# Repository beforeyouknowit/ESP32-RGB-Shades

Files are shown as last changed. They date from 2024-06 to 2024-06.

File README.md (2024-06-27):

# ESP32 RGB Shades
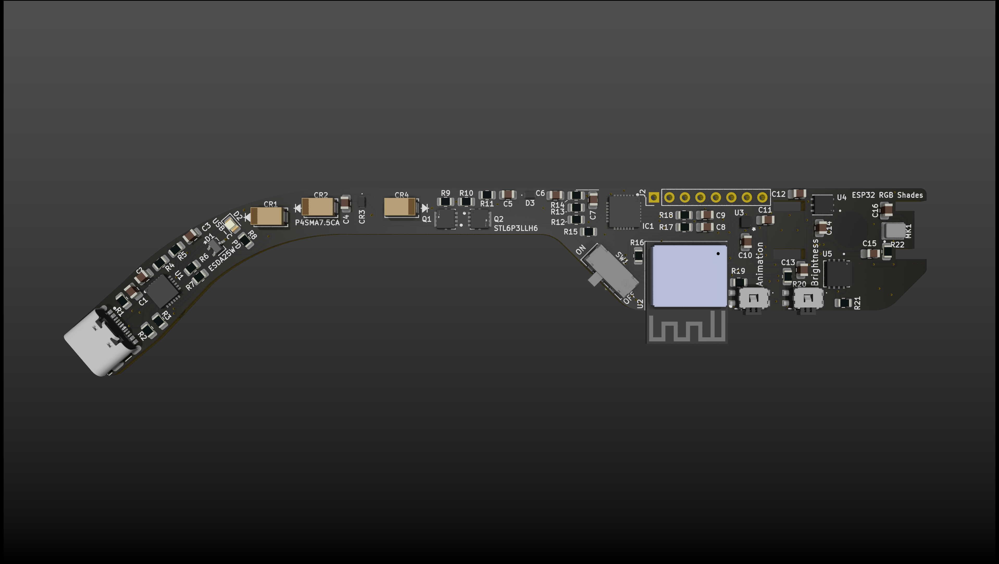
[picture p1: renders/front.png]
ESP32 RGB Shades front printed circuit board render

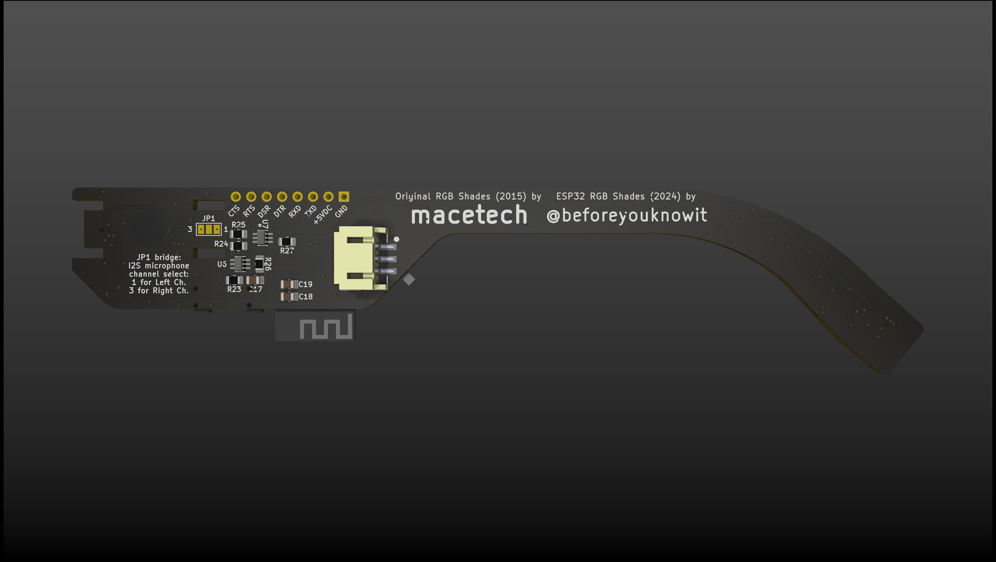
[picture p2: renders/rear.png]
ESP32 RGB Shades rear printed circuit board render


This repo currently represents an electronics update, based on the  ESP32 Pico Mini, as a redesign of [macetech/RGBShades](https://github.com/macetech/RGBShades) from 2015.

I was one of the Kickstarter backers of macetech's original campaign for "RGB Shades", described here: https://www.kickstarter.com/projects/macetech/rgb-led-shades

Redesigned in KiCad 8.x, based on original Eagle files from Macetech's website.

## Features
New electronics include:
- USB-C PD via STUSB4500 IC, which negotiates with USB-C PD supplies (e.g. modern power bank batteries and wall adapters) for 20V output, up to 5A, or 100W.
- TDK ICS-43434 microphone, with I2S digital output, for onboard audio analysis and beat detection.
- Jumper for selecting microphone digital output as left (default) or right channel audio over I2S.
- 5V, 1.5A linear voltage regulator for powering WS2812B LEDs from 20V USB-C PD supply.
- 3.3V, 1.0A linear voltage regulator for powering onboard ICs.
- Slight changes to rear ear-stem geometry to accommodate new USB-C PD IC and passives.

What hasn't changed:
- Same power switch.
- Same pushbuttons. (Now labeled as "Animate" and "Brightness".)
- Same CP2102N USB to UART, with "full remote reset" capabilities, making firmware flashing just as easy.
- Same 0.1" (DuPont connector/header) through-holes for direct CP2102N debug, e.g. for bypassing USB.
- Same JST connector to existing RGBShades display, i.e. the front part of the glasses assembly.
- Same glasses assembly hardware positions; meant as a direct upgrade for existing RGBShades owners.

## License
This project is licensed under CERN-OHL-S 2.0 or later version. See the LICENSE file for details.

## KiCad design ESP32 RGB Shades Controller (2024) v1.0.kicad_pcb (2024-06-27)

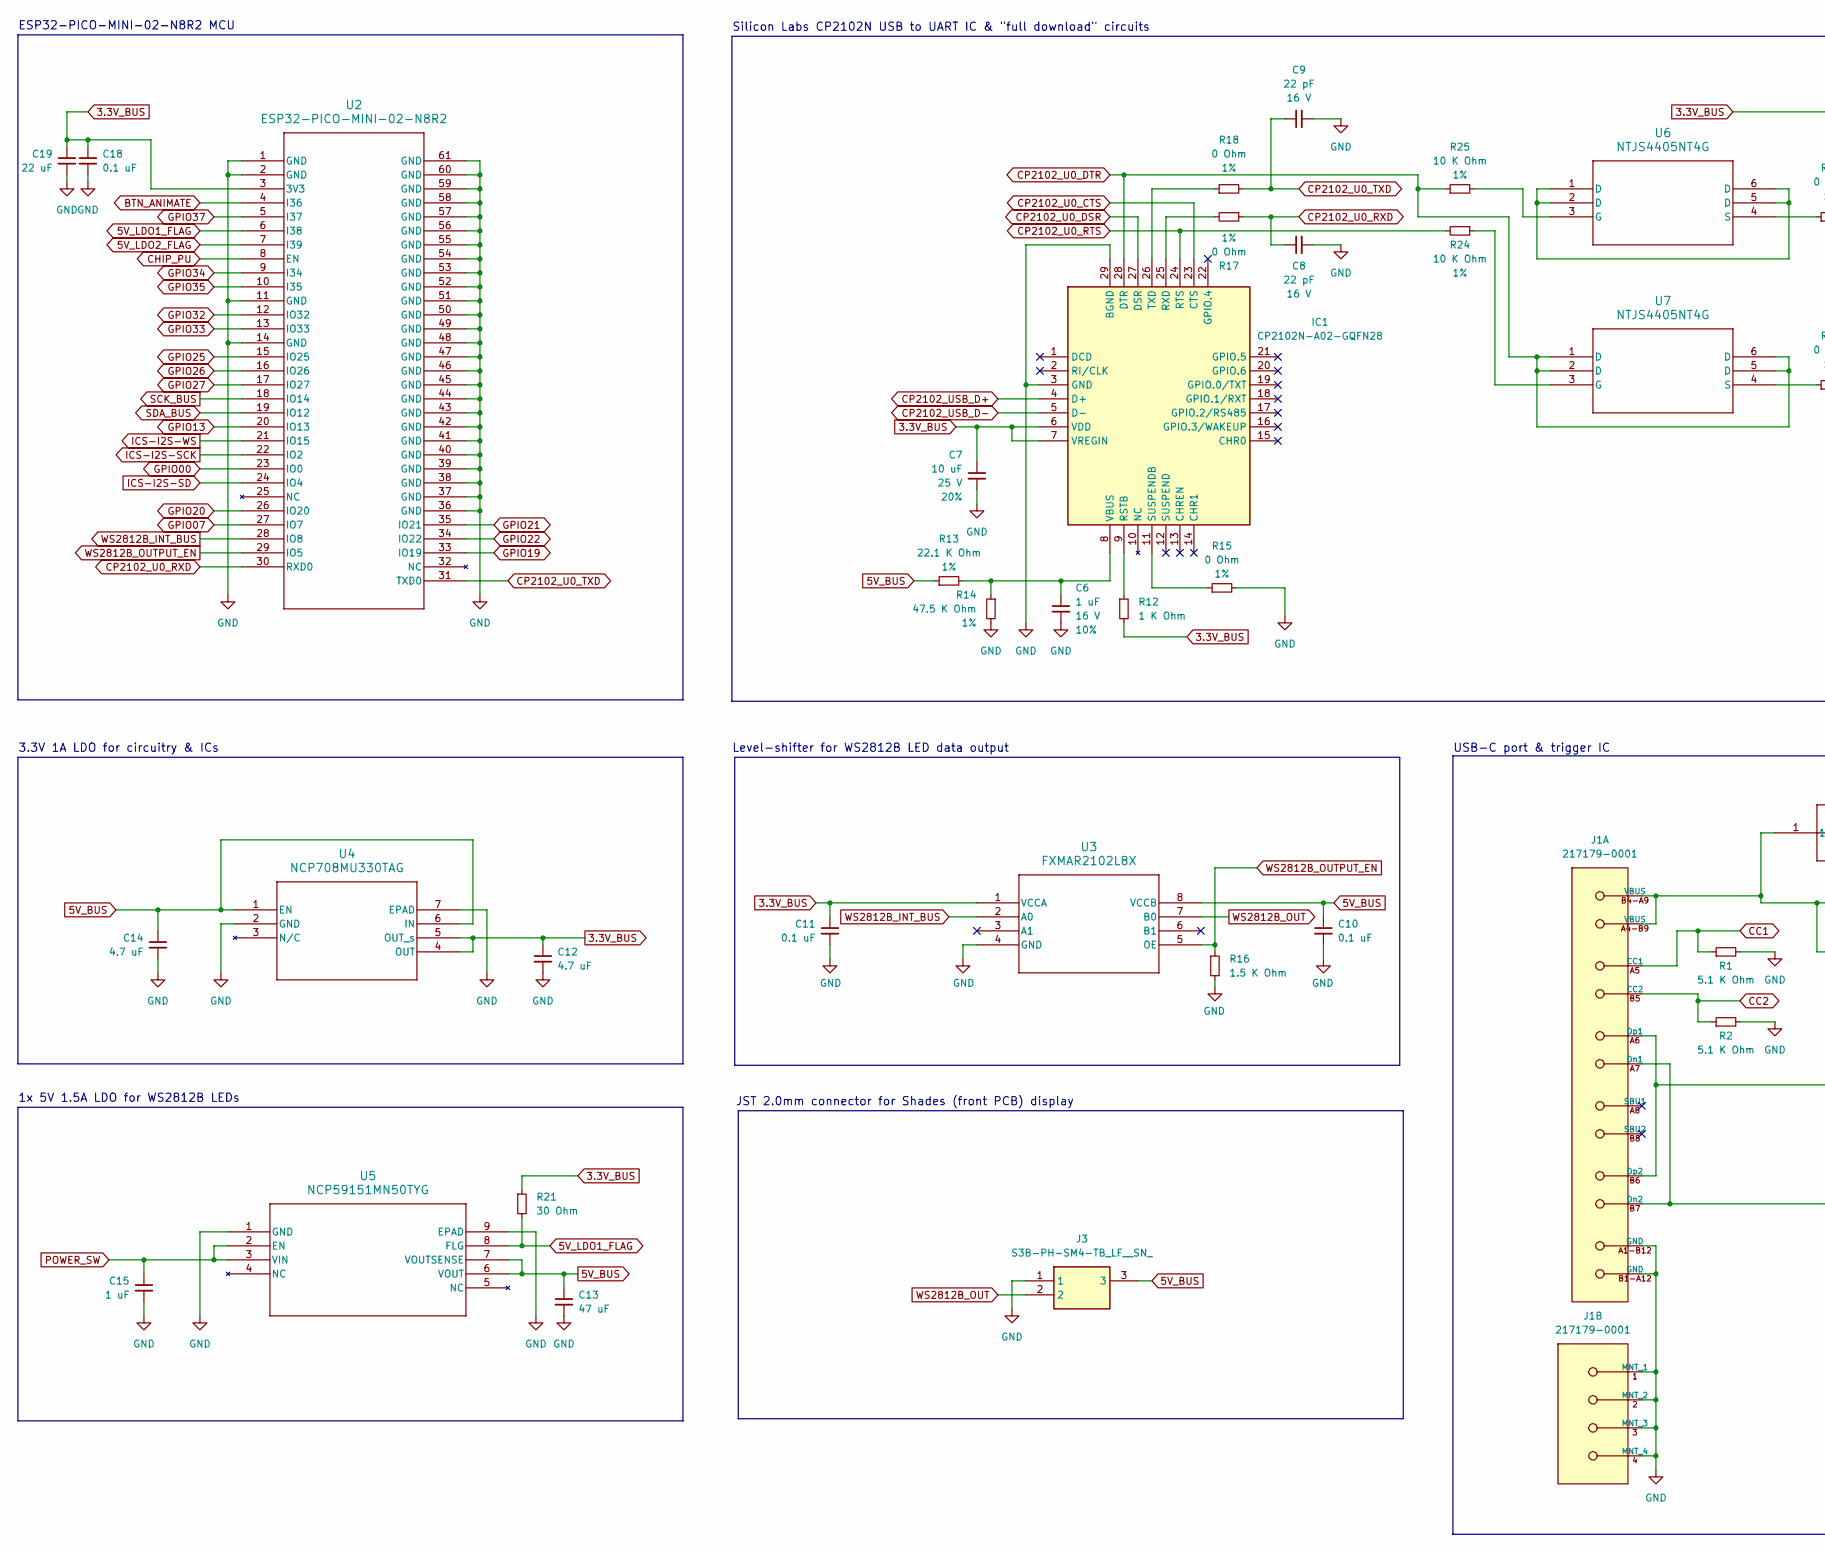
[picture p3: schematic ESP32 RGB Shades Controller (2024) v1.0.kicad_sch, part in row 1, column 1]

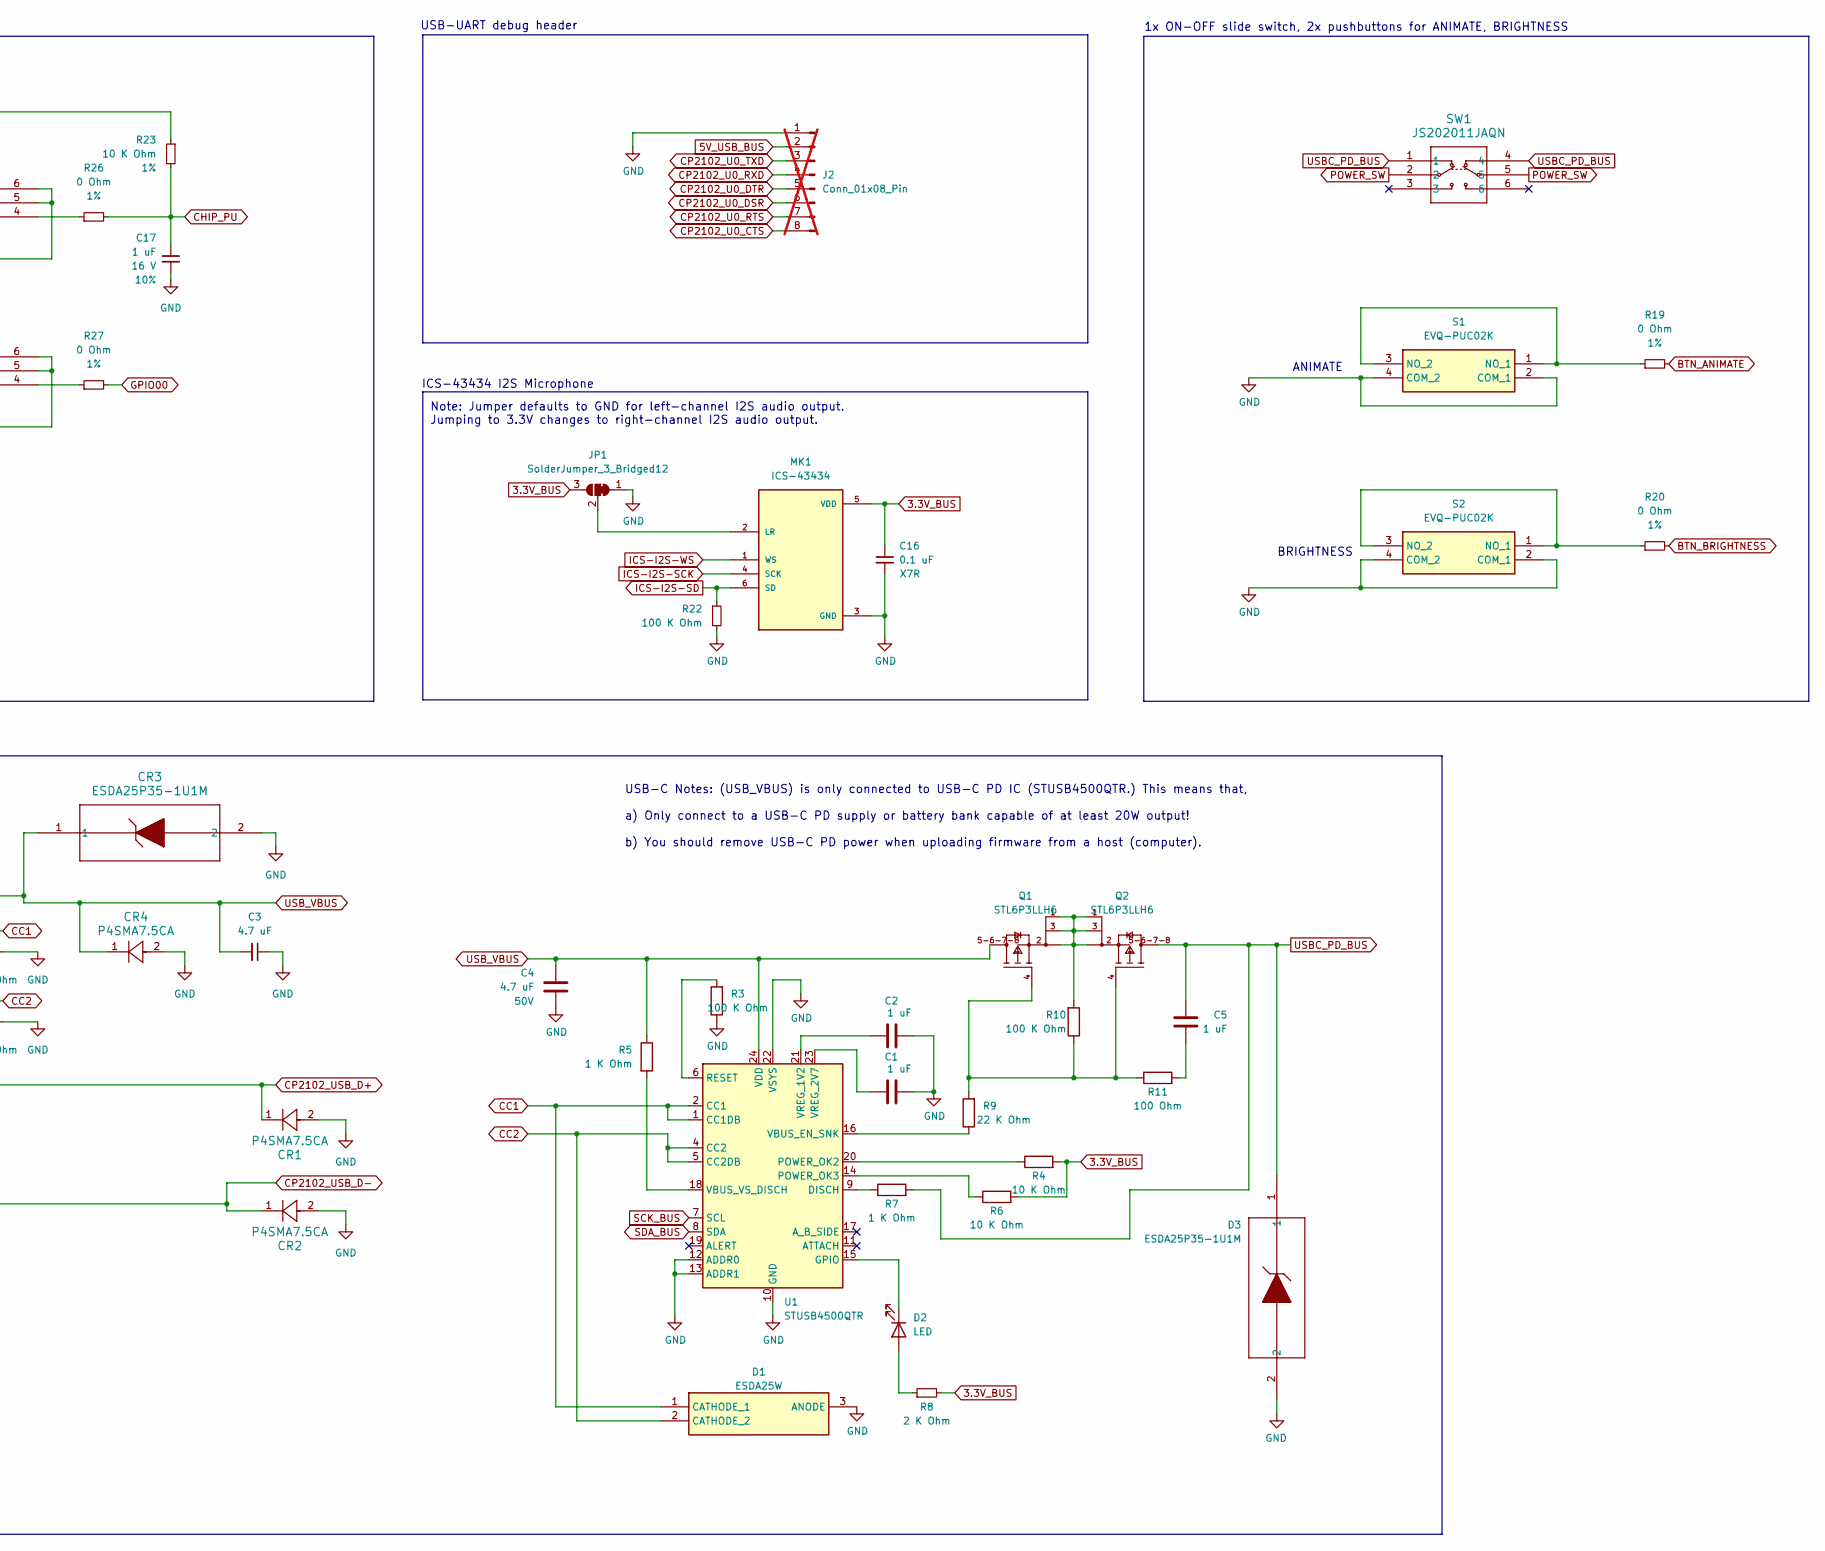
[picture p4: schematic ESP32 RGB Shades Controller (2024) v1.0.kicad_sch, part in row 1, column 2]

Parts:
C1, C2, C5: 1 uF; C_0805_2012Metric; MPN1 CC0805KRX7R7BB104
C3, C12, C14: 4.7 uF; C_0805_2012Metric
C4: 4.7 uF; C_0805_2012Metric; Voltage 50V; MPN1 CC0805KRX7R7BB104
C6, C17: 1 uF; C_0805_2012Metric; Voltage 16 V; Tolerance 10%
C7: 10 uF; C_0805_2012Metric; Voltage 25 V; Tolerance 20%
C8, C9: 22 pF; C_0805_2012Metric; Voltage 16 V
C10, C11, C16, C18: 0.1 uF; C_0805_2012Metric
C13: 47 uF; C_0805_2012Metric
C15: 1 uF; C_0805_2012Metric
C19: 22 uF; C_0805_2012Metric
CR1, CR2, CR4: P4SMA7.5CA; P4SMASeries_LTF
CR3: ESDA25P35-1U1M; ESDA25P351U1M
D1: ESDA25W; SOT323-3L_STM; Manufacturer_Part_Number ESDA25W; Mouser Part Number 511-ESDA25W
D2: LED; LED_0805_2012Metric
D3: ESDA25P35-1U1M; ESDA25P351U1M; Manufacturer_Part_Number ESDA25P35-1U1M; Mouser Part Number 511-ESDA25P35-1U1M
IC1: CP2102N-A02-GQFN28; QFN50P500X500X80-29N-D; Manufacturer_Part_Number CP2102N-A02-GQFN28; Mouser Part Number 634-CP2102NA02GQFN28
J1: 217179-0001; Molex-217179-0001-MFG; current rating 1.25A; voltage rating 30V; mouser part number 538-217179-0001; digikey description CONN RCP USB2.0 TYP C 24P SMD RA
J2: Conn_01x08_Pin; PinHeader_1x08_P2.54mm_Vertical; not fitted
J3: S3B-PH-SM4-TB_LF__SN_; S3B-PH-SM4-TB; Manufacturer_Part_Number S3B-PH-SM4-TB(LF)(SN)
JP1: SolderJumper_3_Bridged12; SolderJumper-3_P1.3mm_Bridged2Bar12_Pad1.0x1.5mm_NumberLabe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
MK1: ICS-43434; MIC_ICS-43434
Q1, Q2: STL6P3LLH6; STMicroelectronics-PowerFLAT3.3x3.3-8465286-0-2-MFG; mouser part number 511-STL6P3LLH6; digikey description MOSFET P-CH 30V 6A POWERFLAT
R1, R2: 5.1 K Ohm; R_0805_2012Metric
R3, R10, R22: 100 K Ohm; R_0805_2012Metric
R4, R6: 10 K Ohm; R_0805_2012Metric
R5, R7, R12: 1 K Ohm; R_0805_2012Metric
R8: 2 K Ohm; R_0805_2012Metric
R9: 22 K Ohm; R_0805_2012Metric
R11: 100 Ohm; R_0805_2012Metric
R13: 22.1 K Ohm; R_0805_2012Metric; Tolerance 1%
R14: 47.5 K Ohm; R_0805_2012Metric; Tolerance 1%
R15, R17, R18, R19, R20, R26, R27: 0 Ohm; R_0805_2012Metric; Tolerance 1%
R16: 1.5 K Ohm; R_0805_2012Metric
R21: 30 Ohm; R_0805_2012Metric
R23, R24, R25: 10 K Ohm; R_0805_2012Metric; Tolerance 1%
S1, S2: EVQ-PUC02K; EVQPUC02K; Manufacturer_Part_Number EVQ-PUC02K; Mouser Part Number 667-EVQ-PUC02K
SW1: JS202011JAQN; SW_DPDT_CK_JS202011JCQN
U1: STUSB4500QTR; QFN50P400X400X100-25N-D
U2: ESP32-PICO-MINI-02-N8R2; ESP32-PICO-MINI-02_EXP
U3: FXMAR2102L8X; FXMAR2102L8X_ONS-M
U4: NCP708MU330TAG; UDFN6_3X3_ONS-M
U5: NCP59151MN50TYG; DFN8_ONS-M
U6, U7: NTJS4405NT4G; SOT-363-6_2P2X1P35_ONS-M

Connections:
3.3V_BUS: C7.1, C11.1, C12.1, C16.1, C18.1, C19.1, IC1.6 (VDD), IC1.7 (VREGIN), JP1.3 (B), MK1.5 (VDD), R4.2, R6.2, R8.2, R12.2, R21.1, R23.1, U2.3 (3V3), U3.1 (VCCA), U4.4 (OUT), U4.5 (OUT_s)
5V_BUS: C10.1, C13.1, C14.1, J3.3, R13.1, U3.8 (VCCB), U4.1 (EN), U4.6 (IN), U5.6 (VOUT), U5.7 (VOUTSENSE)
5V_LDO1_FLAG: R21.2, U2.6 (I38), U5.8 (FLG)
5V_LDO2_FLAG: U2.7 (I39)
5V_USB_BUS: J2.2
BTN_ANIMATE: R19.2, U2.4 (I36)
BTN_BRIGHTNESS: R20.2
CC1: D1.1 (CATHODE_1), J1.A5 (CC1), R1.1, U1.1 (CC1DB), U1.2 (CC1)
CC2: D1.2 (CATHODE_2), J1.B5 (CC2), R2.1, U1.4 (CC2), U1.5 (CC2DB)
CHIP_PU: C17.1, R23.2, R26.2, U2.8 (EN)
CP2102_U0_CTS: IC1.23 (CTS), J2.8
CP2102_U0_DSR: IC1.27 (DSR), J2.6
CP2102_U0_DTR: IC1.28 (DTR), J2.5, R25.1, U7.1 (D), U7.2 (D), U7.5 (D), U7.6 (D)
CP2102_U0_RTS: IC1.24 (RTS), J2.7, R24.2
CP2102_U0_RXD: C8.1, J2.4, R17.1, U2.30 (RXD0)
CP2102_U0_TXD: C9.1, J2.3, R18.2, U2.31 (TXD0)
CP2102_USB_D+: CR1.1, IC1.4 (D+), J1.A6 (Dp1), J1.B6 (Dp2)
CP2102_USB_D-: CR2.1, IC1.5 (D-), J1.A7 (Dn1), J1.B7 (Dn2)
GND: C1.2, C2.2, C3.1, C4.2, C6.2, C7.2, C8.2, C9.2, C10.2, C11.2, C12.2, C13.2, C14.2, C15.2, C16.2, C17.2, C18.2, C19.2, CR1.2, CR2.2, CR3.2, CR4.2, D1.3 (ANODE), D3.2, IC1.3 (GND), IC1.29 (BGND), J1.1 (MNT_1), J1.2 (MNT_2), J1.3 (MNT_3), J1.4 (MNT_4), J1.A1-B12 (GND), J1.B1-A12 (GND), J2.1, J3.1, JP1.1 (A), MK1.3 (GND), R1.2, R2.2, R3.1, R14.2, R15.2, R16.2, R22.2, S1.2 (COM_1), S1.4 (COM_2), S2.2 (COM_1), S2.4 (COM_2), U1.10 (GND), U1.12 (ADDR0), U1.13 (ADDR1), U1.22 (VSYS), U1.25 (GND), U2.1 (GND), U2.2 (GND), U2.11 (GND), U2.14 (GND), U2.36 (GND), U2.37 (GND), U2.38 (GND), U2.39 (GND), U2.40 (GND), U2.41 (GND), U2.42 (GND), U2.43 (GND), U2.44 (GND), U2.45 (GND), U2.46 (GND), U2.47 (GND), U2.48 (GND), U2.49 (GND), U2.50 (GND), U2.51 (GND), U2.52 (GND), U2.53 (GND), U2.54 (GND), U2.55 (GND), U2.56 (GND), U2.57 (GND), U2.58 (GND), U2.59 (GND), U2.60 (GND), U2.61 (GND), U3.4 (GND), U4.2 (GND), U4.7 (EPAD), U5.1 (GND), U5.9 (EPAD)
GPIO00: R27.2, U2.23 (IO0)
GPIO07: U2.27 (IO7)
GPIO13: U2.20 (IO13)
GPIO19: U2.33 (IO19)
GPIO20: U2.26 (IO20)
GPIO21: U2.35 (IO21)
GPIO22: U2.34 (IO22)
GPIO25: U2.15 (IO25)
GPIO26: U2.16 (IO26)
GPIO27: U2.17 (IO27)
GPIO32: U2.12 (IO32)
GPIO33: U2.13 (IO33)
GPIO34: U2.9 (I34)
GPIO35: U2.10 (I35)
GPIO37: U2.5 (I37)
ICS-I2S-SCK: MK1.4 (SCK), U2.22 (IO2)
ICS-I2S-SD: MK1.6 (SD), R22.1, U2.24 (IO4)
ICS-I2S-WS: MK1.1 (WS), U2.21 (IO15)
unnamed: C5.1, R11.2
unnamed: D2.2 (A), R8.1
unnamed: D2.1 (K), U1.15 (GPIO)
unnamed: IC1.9 (RSTB), R12.1
unnamed: IC1.25 (RXD), R17.2
unnamed: IC1.11 (SUSPENDB), R15.1
unnamed: IC1.26 (TXD), R18.1
unnamed: C6.1, IC1.8 (VBUS), R13.2, R14.1
unnamed: JP1.2 (C), MK1.2 (LR)
unnamed: Q1.4 (G), Q2.4 (G), R9.2, R10.1, R11.1
unnamed: Q1.1 (S), Q1.2 (S), Q1.3 (S), Q2.1 (S), Q2.2 (S), Q2.3 (S), R10.2
unnamed: R19.1, S1.1 (NO_1), S1.3 (NO_2)
unnamed: R20.1, S2.1 (NO_1), S2.3 (NO_2)
unnamed: R7.1, U1.9 (DISCH)
unnamed: R4.1, U1.20 (POWER_OK2)
unnamed: R6.1, U1.14 (POWER_OK3)
unnamed: R3.2, U1.6 (RESET)
unnamed: R9.1, U1.16 (VBUS_EN_SNK)
unnamed: R5.2, U1.18 (VBUS_VS_DISCH)
unnamed: C2.1, U1.21 (VREG_1V2)
unnamed: C1.1, U1.23 (VREG_2V7)
unnamed: U6.1 (D), U6.2 (D), U6.5 (D), U6.6 (D)
unnamed: R25.2, U6.3 (G)
unnamed: R26.1, U6.4 (S)
unnamed: R24.1, U7.3 (G)
unnamed: R27.1, U7.4 (S)
POWER_SW: C15.1, SW1.2, SW1.5, U5.2 (EN), U5.3 (VIN)
SCK_BUS: U1.7 (SCL), U2.18 (IO14)
SDA_BUS: U1.8 (SDA), U2.19 (IO12)
USBC_PD_BUS: C5.2, D3.1, Q2.5-6-7-8 (D), R7.2, SW1.1, SW1.4
USB_VBUS: C3.2, C4.1, CR3.1, CR4.1, J1.A4-B9 (VBUS), J1.B4-A9 (VBUS), Q1.5-6-7-8 (D), R5.1, U1.24 (VDD)
WS2812B_INT_BUS: U2.28 (IO8), U3.2 (A0)
WS2812B_OUT: J3.2, U3.7 (B0)
WS2812B_OUTPUT_EN: R16.1, U2.29 (IO5), U3.5 (OE)

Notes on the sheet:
JST 2.0mm connector for Shades (front PCB) display
USB-C Notes: (USB_VBUS) is only connected to USB-C PD IC (STUSB4500QTR.) This means that, a) Only connect to a USB-C PD supply or battery bank capable of at least 20W output! b) You should remove USB-C PD power when uploading firmware from a host (computer).
Silicon Labs CP2102N USB to UART IC & "full download" circuits
1x 5V 1.5A LDO for WS2812B LEDs
USB-C port & trigger IC
Note: Jumper defaults to GND for left-channel I2S audio output. Jumping to 3.3V changes to right-channel I2S audio output.
ANIMATE
ICS-43434 I2S Microphone
Level-shifter for WS2812B LED data output
3.3V 1A LDO for circuitry & ICs
ESP32-PICO-MINI-02-N8R2 MCU
BRIGHTNESS
USB-UART debug header
1x ON-OFF slide switch, 2x pushbuttons for ANIMATE, BRIGHTNESS

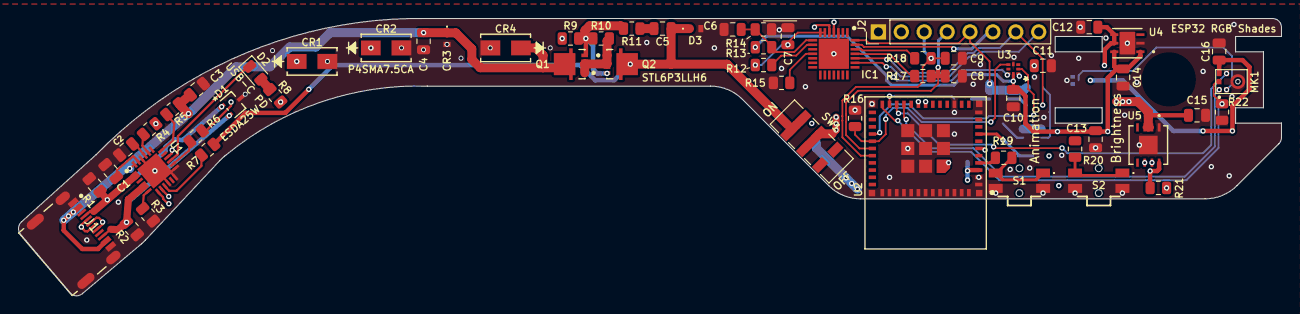
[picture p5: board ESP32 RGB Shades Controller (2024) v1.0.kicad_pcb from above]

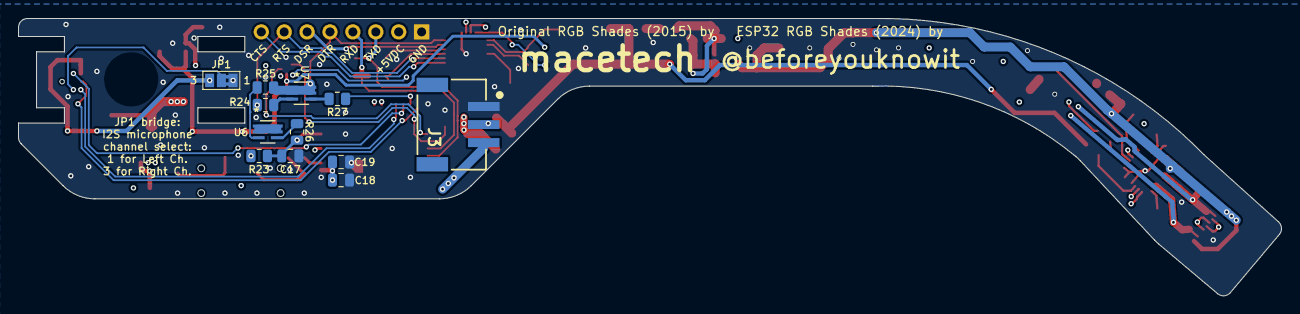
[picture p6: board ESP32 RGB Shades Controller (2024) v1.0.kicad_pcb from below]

Board: 4 copper layers, 140.1 x 30.8 mm, 71 parts (12 on the bottom side), 54 nets.

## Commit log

2024-06-27 Initial repo commit with v1.0 design.
    [ESP32 RGB Shades Controller (2024) v1.0.kicad_pcb, ESP32 RGB Shades Controller (2024) v1.0.kicad_sch]
2024-06-27 Saved previous LED XY map.
2024-06-27 Update README.md to include renders of PCB.
